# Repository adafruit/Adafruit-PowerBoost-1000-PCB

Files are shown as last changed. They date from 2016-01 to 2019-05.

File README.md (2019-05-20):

## Adafruit PowerBoost 1000 Basic PCB
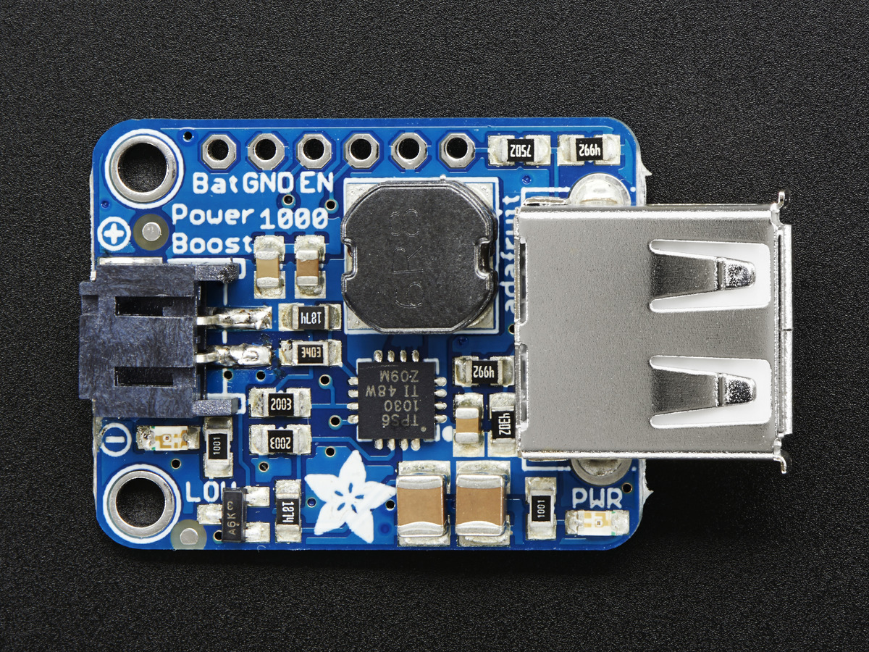
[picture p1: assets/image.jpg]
<a href="http://www.adafruit.com/products/2030"><br/>
Click here to purchase one from the Adafruit shop</a>

PowerBoost is the perfect power supply for your power-hungry portable project! This little DC/DC boost converter module can run from 1.8V batteries or higher, and convert that voltage to 5.2V DC for running your 5V projects. With a beefy 4A DC/DC converter, it can give you 1A+ from as low as 2V. 

Like our popular 5V 1A USB wall adapter, we tweaked the output to be 5.2V instead of a straight-up 5.0V so that there's a little bit of 'headroom' long cables, high draw, the addition of a diode on the output if you wish, etc. The 5.2V is safe for all 5V-powered electronics like Arduino, Raspberry Pi, or BeagleBone while preventing icky brown-outs during high current draw because of USB cable resistance.

The PowerBoost 1000 has at the heart a TPS61030 boost converter from TI. This boost converter chip has some really nice extras such as low battery detection, 4A internal switch, synchronous conversion, excellent efficiency, and 700KHz high-frequency operation. Check out these specs!

PCB files for Adafruit PowerBoost 1000 Basic (no charger)
- https://www.adafruit.com/products/2030

### License

Adafruit invests time and resources providing this open source design, please support Adafruit and open-source hardware by purchasing products from [Adafruit](https://www.adafruit.com)!

All text above must be included in any redistribution

Designed by Limor Fried/Ladyada for Adafruit Industries.
Creative Commons Attribution/Share-Alike, all text above must be included in any redistribution. 
See license.txt for additional information.

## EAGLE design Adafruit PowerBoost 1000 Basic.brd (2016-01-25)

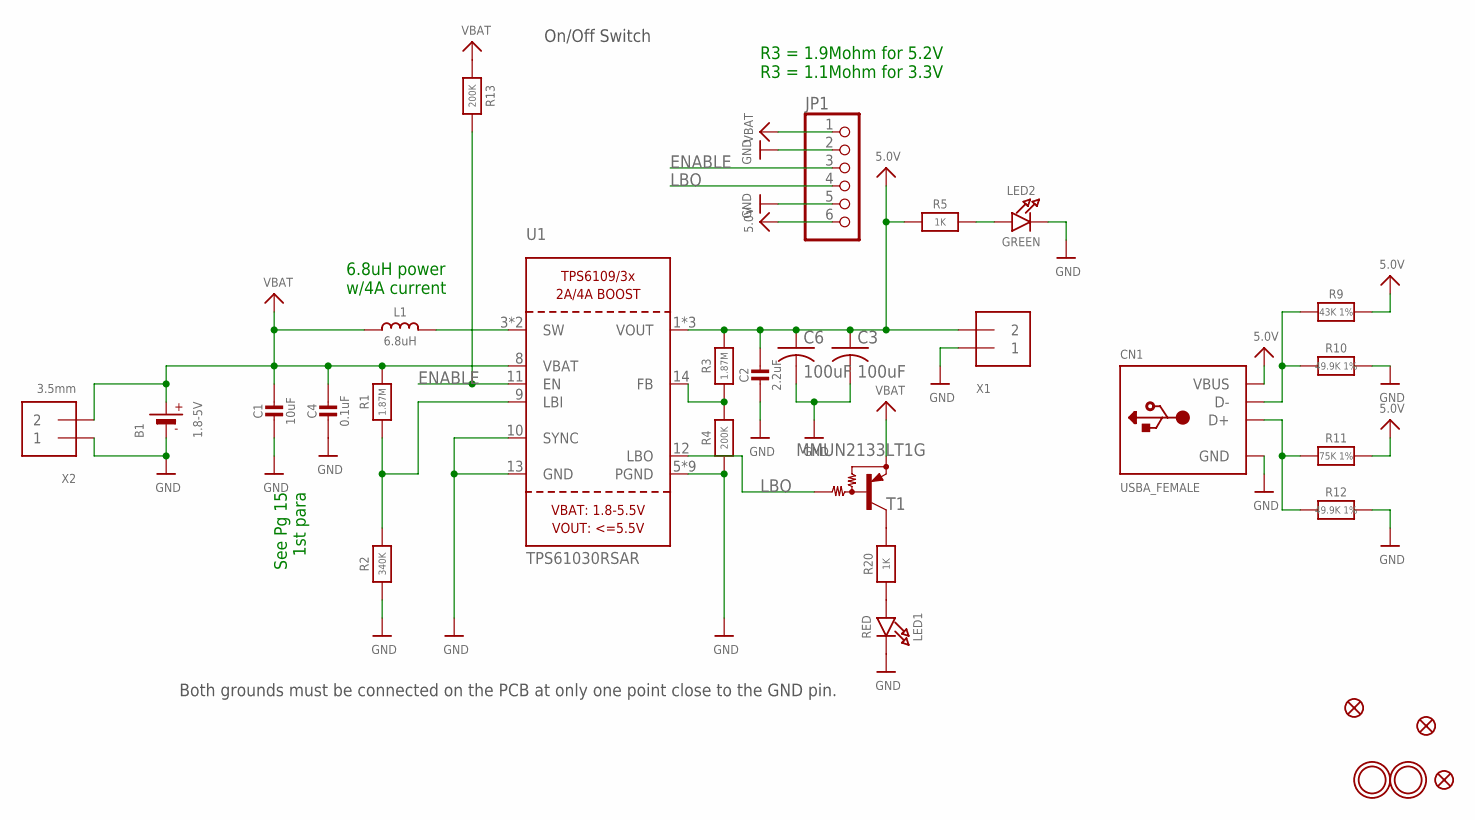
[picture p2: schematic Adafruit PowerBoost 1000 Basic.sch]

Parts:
B1: 1.8-5V; JSTPH2
C1: 10uF; 0805-NO
C2: 2.2uF; 0805-NO
C3, C6: 100uF; C1210
C4: 0.1uF; 0805-NO
CN1: USBA_FEMALE; USB_HOST-PTH
FID1, FID2, FID3: FIDUCIAL""; FIDUCIAL_1MM
JP1: PINHD-1X6CB; 1X06-CLEANBIG
L1: 6.8uH; INDUCTOR_8X8MM
LED1: RED; CHIPLED_0805_NOOUTLINE
LED2: GREEN; CHIPLED_0805_NOOUTLINE
R1, R3: 1.87M; _0805MP
R2: 340K; _0805MP
R4, R13: 200K; 0805-NO
R5, R20: 1K; 0805-NO
R9: 43K 1%; 0805-NO
R10, R12: 49.9K 1%; 0805-NO
R11: 75K 1%; 0805-NO
T1: MMUN2133LT1G; SC59-BEC
U1: TPS61030RSAR; PVQFN-16
U$10, U$11: MOUNTINGHOLE2.5; MOUNTINGHOLE_2.5_PLATED
X1: TERMBLOCK_1X2; TERMBLOCK_1X2-3.5MM
X2: 3.5mm; TERMBLOCK_1X2-3.5MM

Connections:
5.0V: C2.1, C3.1, C6.1, CN1.VBUS, JP1.6, R3.2, R5.1, R9.2, R11.2, U1.1 (VOUT), U1.15 (VOUT), U1.16 (VOUT), X1.2
D+: CN1.D+, R11.1, R12.1
D-: CN1.D-, R9.1, R10.1
ENABLE: JP1.3, R13.2, U1.11 (EN)
GND: B1.1 (-), C1.2, C2.2, C3.2, C4.2, C6.2, CN1.GND, JP1.2, JP1.5, LED1.C, LED2.C, R2.1, R4.1, R10.2, R12.2, U1.5 (PGND), U1.6 (PGND), U1.7 (PGND), U1.10 (SYNC), U1.13 (GND), U1.P$18 (PGND), U1.P$19 (PGND), U1.P$20 (PGND), U1.P$21 (PGND), U1.P$22 (PGND), U1.THERMAL (PGND), X1.1, X2.1
LBO: JP1.4, T1.B, U1.12 (LBO)
unnamed: L1.P$2 (2), U1.3 (SW), U1.4 (SW)
unnamed: LED1.A, R20.1
unnamed: R1.1, R2.2, U1.9 (LBI)
unnamed: LED2.A, R5.2
unnamed: R3.1, R4.2, U1.14 (FB)
unnamed: R20.2, T1.C
VBAT: B1.2 (+), C1.1, C4.1, JP1.1, L1.P$1 (1), R1.2, R13.1, T1.E, U1.8 (VBAT), X2.2

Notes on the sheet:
Both grounds must be connected on the PCB at only one point close to the GND pin.
On/Off Switch
See Pg 15 1st para
6.8uH power w/4A current
R3 = 1.9Mohm for 5.2V R3 = 1.1Mohm for 3.3V

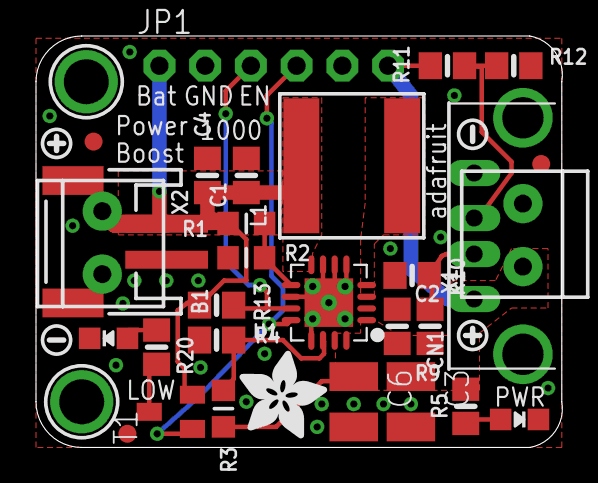
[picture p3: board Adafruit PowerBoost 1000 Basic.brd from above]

Board: 2 copper layers, 29.2 x 22.9 mm, 37 parts (1 on the bottom side), 13 nets.

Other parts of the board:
U$12, U$26: SYMBOL_MINUS
U$13, U$25: SYMBOL_PLUS
U$28, U$33: ADAFRUIT_5MM

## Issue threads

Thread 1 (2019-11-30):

Need pin description

ILIJA-ILIEV, 2019-11-30:
Hello, could you describe pin Vs? Would be better if you give a short description of all pins on the bottom side of the PCB.
Regards
Ilija

ladyada, 2019-11-30:
https://learn.adafruit.com/adafruit-powerboost-1000c-load-share-usb-charge-boost/pinouts

Closed 2019-11-30.

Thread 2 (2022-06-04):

Mount hole dimensions

tkircher, 2022-06-04:
I just noticed that the top hole X is at 0.11" while the bottom X is at 0.10", and sure enough, I looked at my actual Powerboost 1000 board, which I bought recently, and the holes are not lined up.

ladyada, 2022-06-05:
huh! ok we'll check it on the next time we order PCBs!

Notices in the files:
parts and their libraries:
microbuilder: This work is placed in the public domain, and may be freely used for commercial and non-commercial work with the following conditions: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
